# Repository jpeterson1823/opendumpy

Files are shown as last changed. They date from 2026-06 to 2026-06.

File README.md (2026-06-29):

# OpenDumpy: GB/C Dumping Tool

## What is this?
OpenDumpy is an open-source Gameboy and Gameboy Color cartridge dumper.

Planned Features:
- ROM Dump
- SRAM Dump
- SRAM Uploading from file
- Custom Open-Source USB Communication protocol
  - Will have FOSS software interface included in this repo.
- Lots of docs!

## Current Fabrication Status Status

OpenDumpy v1 boards are on order with PCBWay, expected by the middle of July 2026.

Firmware design is in progress. Actual programming to come soon.

## Setup & Building the UF2

### Install Required Packages

For Arch Linux:
- `cmake`
- `python`
- `base-devel`
- `arm-none-eabi-gcc`
- `arm-none-eabi-newlib`
- `arm-none-eabi-binutils`

For apt-based systems:
- `cmake`
- `python3`
- `build-essential`
- `gcc-arm-none-eabi`
- `libnewlib-arm-none-eabi`
- `libstdc++-arm-none-eabi-newlib`

### Cloning the Repo

When cloning this repo, make sure to _recursively_ initialize all submodules:

```
git clone https://github.com/jpeterson1823/opendumpy.git
cd opendumpy
git submodule update --init --recursive
```

### Compiling the Firmware

Assuming all package dependencies have been installed, building should be completed with CMake and Make.

It is recommended to create a build folder as to not muddy up the file tree:

```
mkdir firmware/build
cd firmware/build
cmake ..
make -j4
```

### Uploading the Firmware

Press the BOOTSEL button on OpenDumpy, then plug into USB port of machine. It will mount as a USB drive. Upload the built `opendumpy.uf2` file to the mounted drive. Voila!

## Images

### OpenDumpy v1
<div>
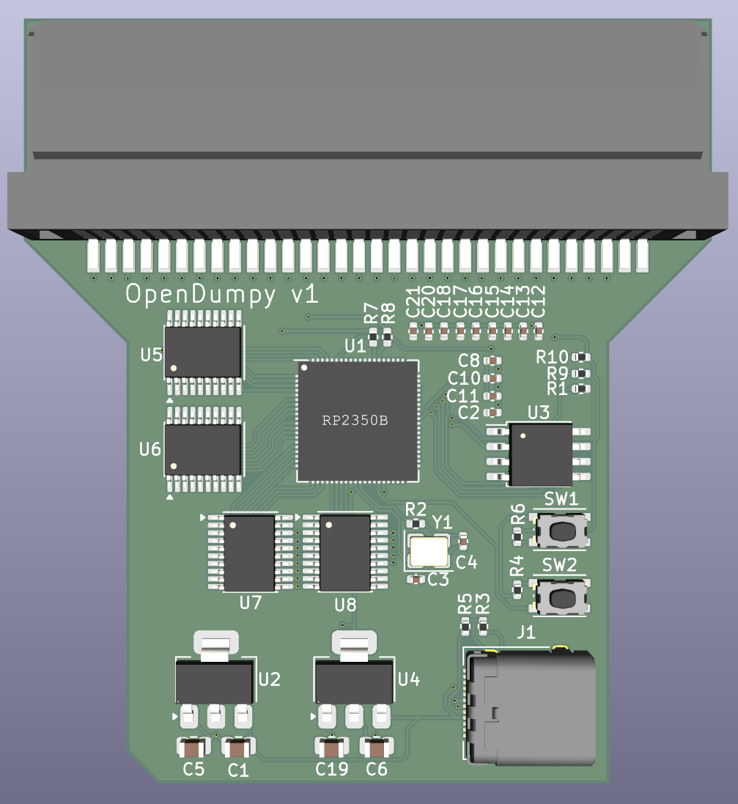
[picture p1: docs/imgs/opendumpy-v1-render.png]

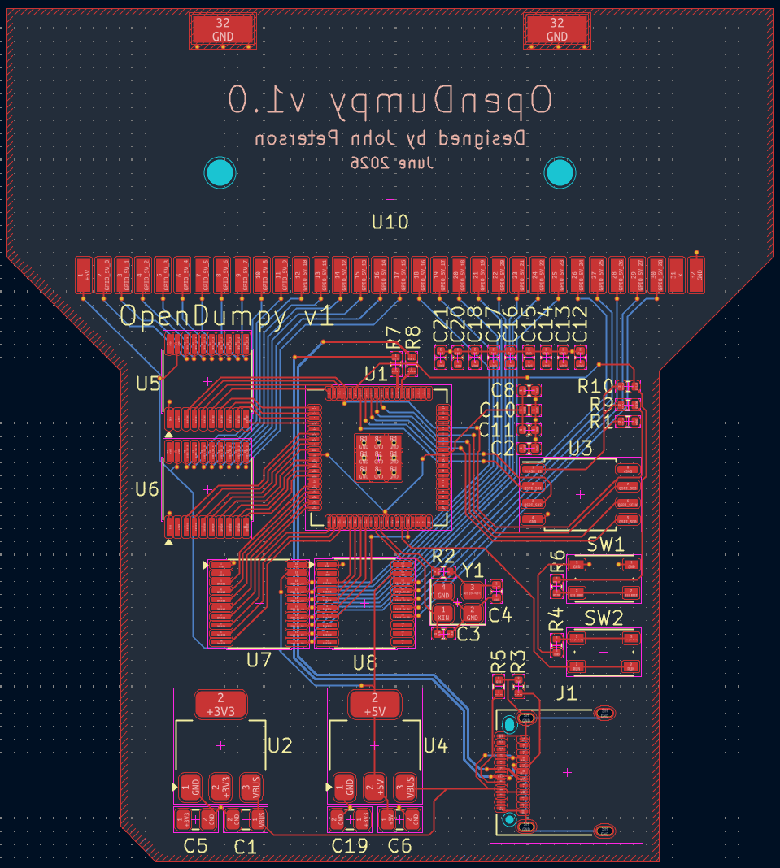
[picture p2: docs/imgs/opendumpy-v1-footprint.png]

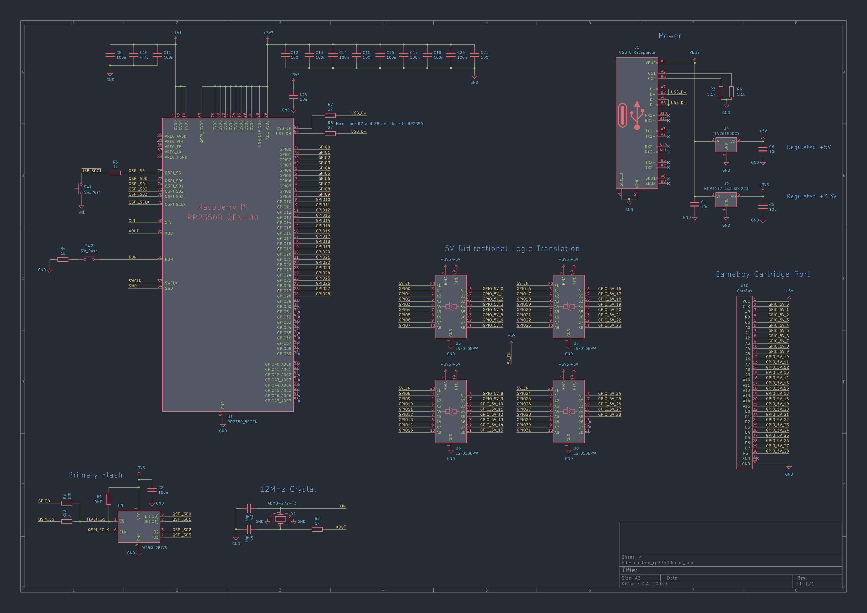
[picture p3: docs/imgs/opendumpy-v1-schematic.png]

</div>

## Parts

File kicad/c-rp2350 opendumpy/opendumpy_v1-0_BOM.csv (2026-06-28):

Id | Designator | Footprint | Quantity | Designation | Supplier and ref
1 | C1, C5, C6, C19 | C_0805_2012Metric | 4 | 10u
2 | C2, C8, C11, C12, C13, C14, C15, C16, C17, C18, C20, C21 | C_0402_1005Metric | 12 | 100n
3 | C3, C4 | C_0402_1005Metric | 2 | 15p
4 | C10 | C_0402_1005Metric | 1 | 4.7u
5 | J1 | USB_C_Receptacle_Amphenol_12401610E4-2A | 1 | USB_C_Receptacle
6 | R1, R9 | R_0402_1005Metric | 2 | DNF
7 | R2, R4, R6 | R_0402_1005Metric | 3 | 1k
8 | R3, R5 | R_0402_1005Metric | 2 | 5.1k
9 | R7, R8 | R_0402_1005Metric | 2 | 27
10 | R10 | R_0402_1005Metric | 1 | 0
11 | SW1, SW2 | SW_Push_1P1T_NO_Vertical_Wuerth_434133025816 | 2 | SW_Push
12 | U1 | RP2350-QFN-80-1EP_10x10_P0.4mm_EP3.4x3.4mm_ThermalVias | 1 | RP2350_80QFN
13 | U2 | SOT-223-3_TabPin2 | 1 | NCP1117-3.3_SOT223
14 | U3 | SOIC-8_5.23x5.23mm_P1.27mm | 1 | W25Q128JVS
15 | U4 | SOT-223-3_TabPin2 | 1 | TLV76150DCY
16 | U5, U6, U7, U8 | TSSOP-20_4.4x6.5mm_P0.65mm | 4 | LSF0108PW
17 | U10 | DSL_Cartridge_Reader | 1 | CartBus
18 | Y1 | Crystal_SMD_3225-4Pin_3.2x2.5mm | 1 | ABM8-272-T3

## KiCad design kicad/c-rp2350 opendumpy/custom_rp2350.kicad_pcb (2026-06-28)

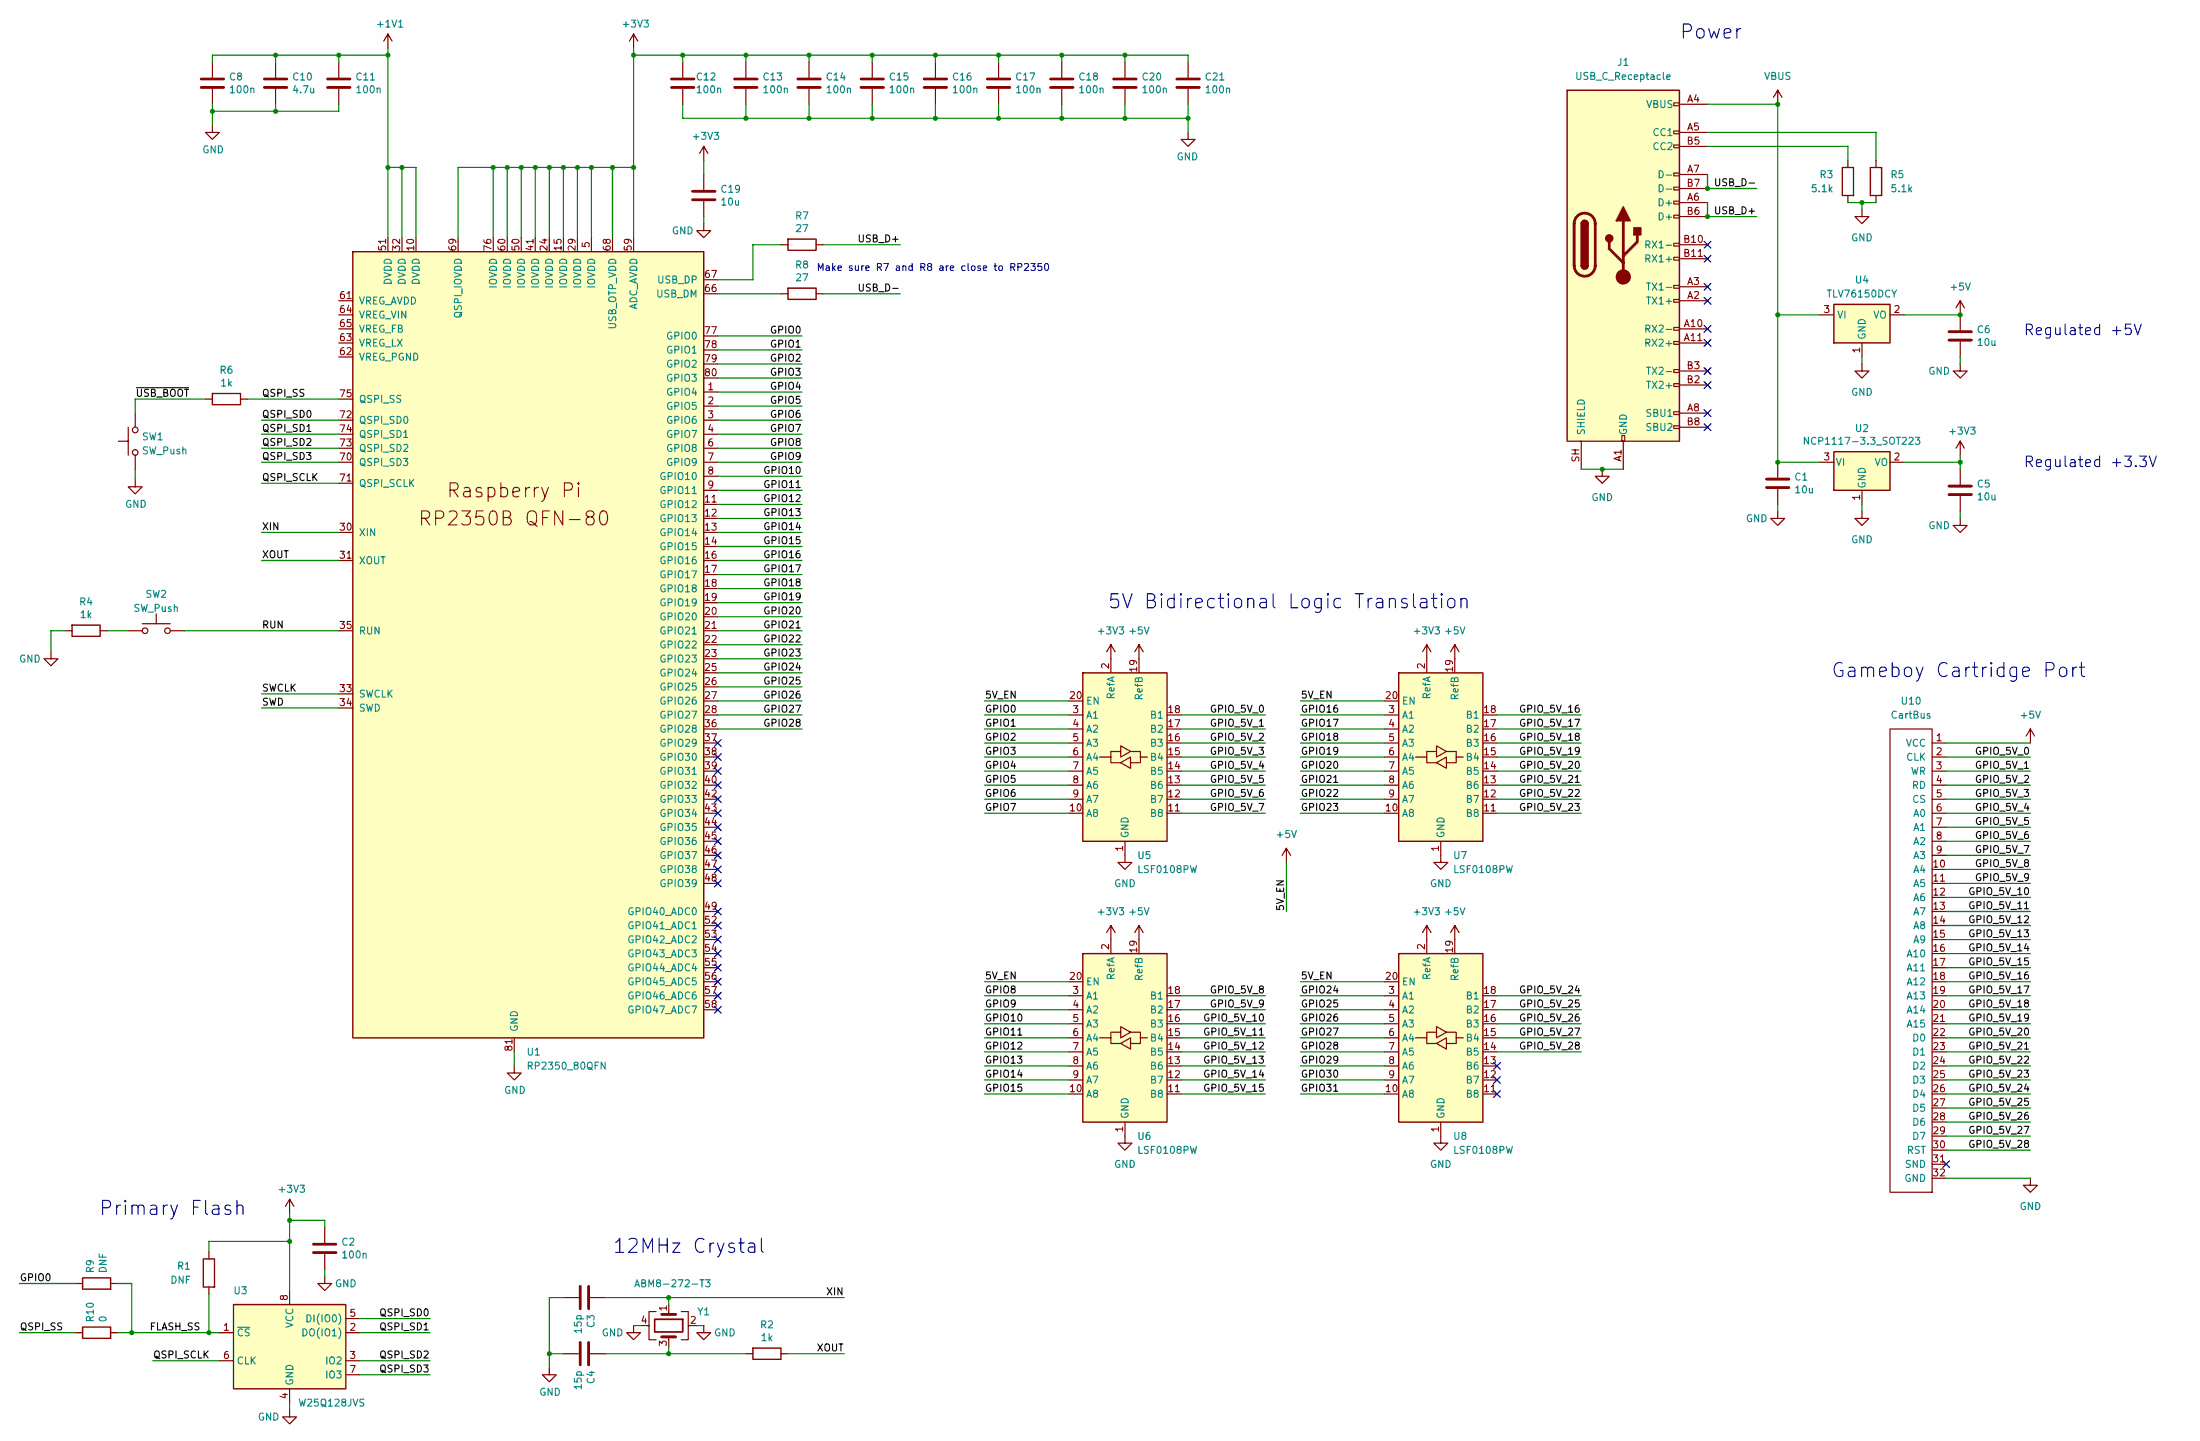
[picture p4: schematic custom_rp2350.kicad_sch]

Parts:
C1, C5, C6, C19: 10u; C_0805_2012Metric
C2, C8, C11, C12, C13, C14, C15, C16, C17, C18, C20, C21: 100n; C_0402_1005Metric
C3, C4: 15p; C_0402_1005Metric
C10: 4.7u; C_0402_1005Metric
J1: USB_C_Receptacle; USB_C_Receptacle_Amphenol_12401610E4-2A
R1, R9: DNF; R_0402_1005Metric
R2, R4, R6: 1k; R_0402_1005Metric
R3, R5: 5.1k; R_0402_1005Metric
R7, R8: 27; R_0402_1005Metric
R10: 0; R_0402_1005Metric
SW1, SW2: SW_Push; SW_Push_1P1T_NO_Vertical_Wuerth_434133025816
U1: RP2350_80QFN; RP2350-QFN-80-1EP_10x10_P0.4mm_EP3.4x3.4mm_ThermalVias
U2: NCP1117-3.3_SOT223; SOT-223-3_TabPin2
U3: W25Q128JVS; SOIC-8_5.23x5.23mm_P1.27mm
U4: TLV76150DCY; SOT-223-3_TabPin2
U5, U6, U7, U8: LSF0108PW; TSSOP-20_4.4x6.5mm_P0.65mm
U10: CartBus; DSL_Cartridge_Reader
Y1: ABM8-272-T3; Crystal_SMD_3225-4Pin_3.2x2.5mm

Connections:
+1V1: C8.1, C10.1, C11.1, U1.10 (DVDD), U1.32 (DVDD), U1.51 (DVDD)
+3V3: C2.1, C5.1, C12.1, C13.1, C14.1, C15.1, C16.1, C17.1, C18.1, C19.1, C20.1, C21.1, R1.1, U1.5 (IOVDD), U1.15 (IOVDD), U1.24 (IOVDD), U1.29 (IOVDD), U1.41 (IOVDD), U1.50 (IOVDD), U1.59 (ADC_AVDD), U1.60 (IOVDD), U1.68 (USB_OTP_VDD), U1.69 (QSPI_IOVDD), U1.76 (IOVDD), U2.2 (VO), U3.8 (VCC), U5.2 (RefA), U6.2 (RefA), U7.2 (RefA), U8.2 (RefA)
+5V: C6.1, U4.2 (VO), U5.19 (RefB), U5.20 (EN), U6.19 (RefB), U6.20 (EN), U7.19 (RefB), U7.20 (EN), U8.19 (RefB), U8.20 (EN), U10.1 (VCC)
/FLASH_SS: R1.2, R9.2, R10.2, U3.1 (~CS)
/GPIO0: R9.1, U1.77 (GPIO0), U5.3 (A1)
/GPIO1: U1.78 (GPIO1), U5.4 (A2)
/GPIO2: U1.79 (GPIO2), U5.5 (A3)
/GPIO3: U1.80 (GPIO3), U5.6 (A4)
/GPIO4: U1.1 (GPIO4), U5.7 (A5)
/GPIO5: U1.2 (GPIO5), U5.8 (A6)
/GPIO6: U1.3 (GPIO6), U5.9 (A7)
/GPIO7: U1.4 (GPIO7), U5.10 (A8)
/GPIO8: U1.6 (GPIO8), U6.3 (A1)
/GPIO9: U1.7 (GPIO9), U6.4 (A2)
/GPIO10: U1.8 (GPIO10), U6.5 (A3)
/GPIO11: U1.9 (GPIO11), U6.6 (A4)
/GPIO12: U1.11 (GPIO12), U6.7 (A5)
/GPIO13: U1.12 (GPIO13), U6.8 (A6)
/GPIO14: U1.13 (GPIO14), U6.9 (A7)
/GPIO15: U1.14 (GPIO15), U6.10 (A8)
/GPIO16: U1.16 (GPIO16), U7.3 (A1)
/GPIO17: U1.17 (GPIO17), U7.4 (A2)
/GPIO18: U1.18 (GPIO18), U7.5 (A3)
/GPIO19: U1.19 (GPIO19), U7.6 (A4)
/GPIO20: U1.20 (GPIO20), U7.7 (A5)
/GPIO21: U1.21 (GPIO21), U7.8 (A6)
/GPIO22: U1.22 (GPIO22), U7.9 (A7)
/GPIO23: U1.23 (GPIO23), U7.10 (A8)
/GPIO24: U1.25 (GPIO24), U8.3 (A1)
/GPIO25: U1.26 (GPIO25), U8.4 (A2)
/GPIO26: U1.27 (GPIO26), U8.5 (A3)
/GPIO27: U1.28 (GPIO27), U8.6 (A4)
/GPIO28: U1.36 (GPIO28), U8.7 (A5)
/GPIO29: U8.8 (A6)
/GPIO30: U8.9 (A7)
/GPIO31: U8.10 (A8)
/GPIO_5V_0: U5.18 (B1), U10.2 (CLK~)
/GPIO_5V_1: U5.17 (B2), U10.3 (WR)
/GPIO_5V_2: U5.16 (B3), U10.4 (RD)
/GPIO_5V_3: U5.15 (B4), U10.5 (CS)
/GPIO_5V_4: U5.14 (B5), U10.6 (A0)
/GPIO_5V_5: U5.13 (B6), U10.7 (A1)
/GPIO_5V_6: U5.12 (B7), U10.8 (A2)
/GPIO_5V_7: U5.11 (B8), U10.9 (A3)
/GPIO_5V_8: U6.18 (B1), U10.10 (A4)
/GPIO_5V_9: U6.17 (B2), U10.11 (A5)
/GPIO_5V_10: U6.16 (B3), U10.12 (A6)
/GPIO_5V_11: U6.15 (B4), U10.13 (A7)
/GPIO_5V_12: U6.14 (B5), U10.14 (A8)
/GPIO_5V_13: U6.13 (B6), U10.15 (A9)
/GPIO_5V_14: U6.12 (B7), U10.16 (A10)
/GPIO_5V_15: U6.11 (B8), U10.17 (A11)
/GPIO_5V_16: U7.18 (B1), U10.18 (A12)
/GPIO_5V_17: U7.17 (B2), U10.19 (A13)
/GPIO_5V_18: U7.16 (B3), U10.20 (A14)
/GPIO_5V_19: U7.15 (B4), U10.21 (A15)
/GPIO_5V_20: U7.14 (B5), U10.22 (D0)
/GPIO_5V_21: U7.13 (B6), U10.23 (D1)
/GPIO_5V_22: U7.12 (B7), U10.24 (D2)
/GPIO_5V_23: U7.11 (B8), U10.25 (D3)
/GPIO_5V_24: U8.18 (B1), U10.26 (D4)
/GPIO_5V_25: U8.17 (B2), U10.27 (D5)
/GPIO_5V_26: U8.16 (B3), U10.28 (D6)
/GPIO_5V_27: U8.15 (B4), U10.29 (D7)
/GPIO_5V_28: U8.14 (B5), U10.30 (RST)
/QSPI_SCLK: U1.71 (QSPI_SCLK), U3.6 (CLK)
/QSPI_SD0: U1.72 (QSPI_SD0), U3.5 (DI(IO0))
/QSPI_SD1: U1.74 (QSPI_SD1), U3.2 (DO(IO1))
/QSPI_SD2: U1.73 (QSPI_SD2), U3.3 (IO2)
/QSPI_SD3: U1.70 (QSPI_SD3), U3.7 (IO3)
/QSPI_SS: R6.1, R10.1, U1.75 (QSPI_SS)
/RUN: SW2.2, U1.35 (RUN)
/SWCLK: U1.33 (SWCLK)
/SWD: U1.34 (SWD)
/USB_D+: J1.A6 (D+), J1.B6 (D+), R7.1
/USB_D-: J1.A7 (D-), J1.B7 (D-), R8.1
/XIN: C3.1, U1.30 (XIN), Y1.1
/XOUT: R2.1, U1.31 (XOUT)
/~USB_BOOT: R6.2, SW1.2
GND: C1.2, C2.2, C3.2, C4.2, C5.2, C6.2, C8.2, C10.2, C11.2, C12.2, C13.2, C14.2, C15.2, C16.2, C17.2, C18.2, C19.2, C20.2, C21.2, J1.A1 (GND), J1.A12 (GND), J1.B1 (GND), J1.B12 (GND), J1.SH (SHIELD), R3.2, R4.2, R5.2, SW1.1, U1.81 (GND), U2.1 (GND), U3.4 (GND), U4.1 (GND), U5.1 (GND), U6.1 (GND), U7.1 (GND), U8.1 (GND), U10.32 (GND), Y1.2, Y1.4
unnamed: C4.1, R2.2, Y1.3
unnamed: J1.A5 (CC1), R5.1
unnamed: J1.B5 (CC2), R3.1
unnamed: R4.1, SW2.1
unnamed: R8.2, U1.66 (USB_DM)
unnamed: R7.2, U1.67 (USB_DP)
VBUS: C1.1, J1.A4 (VBUS), J1.A9 (VBUS), J1.B4 (VBUS), J1.B9 (VBUS), U2.3 (VI), U4.3 (VI)

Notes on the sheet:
Regulated +5V
Make sure R7 and R8 are close to RP2350
5V Bidirectional Logic Translation
Regulated +3.3V
Power
Gameboy Cartridge Port
Primary Flash
12MHz Crystal

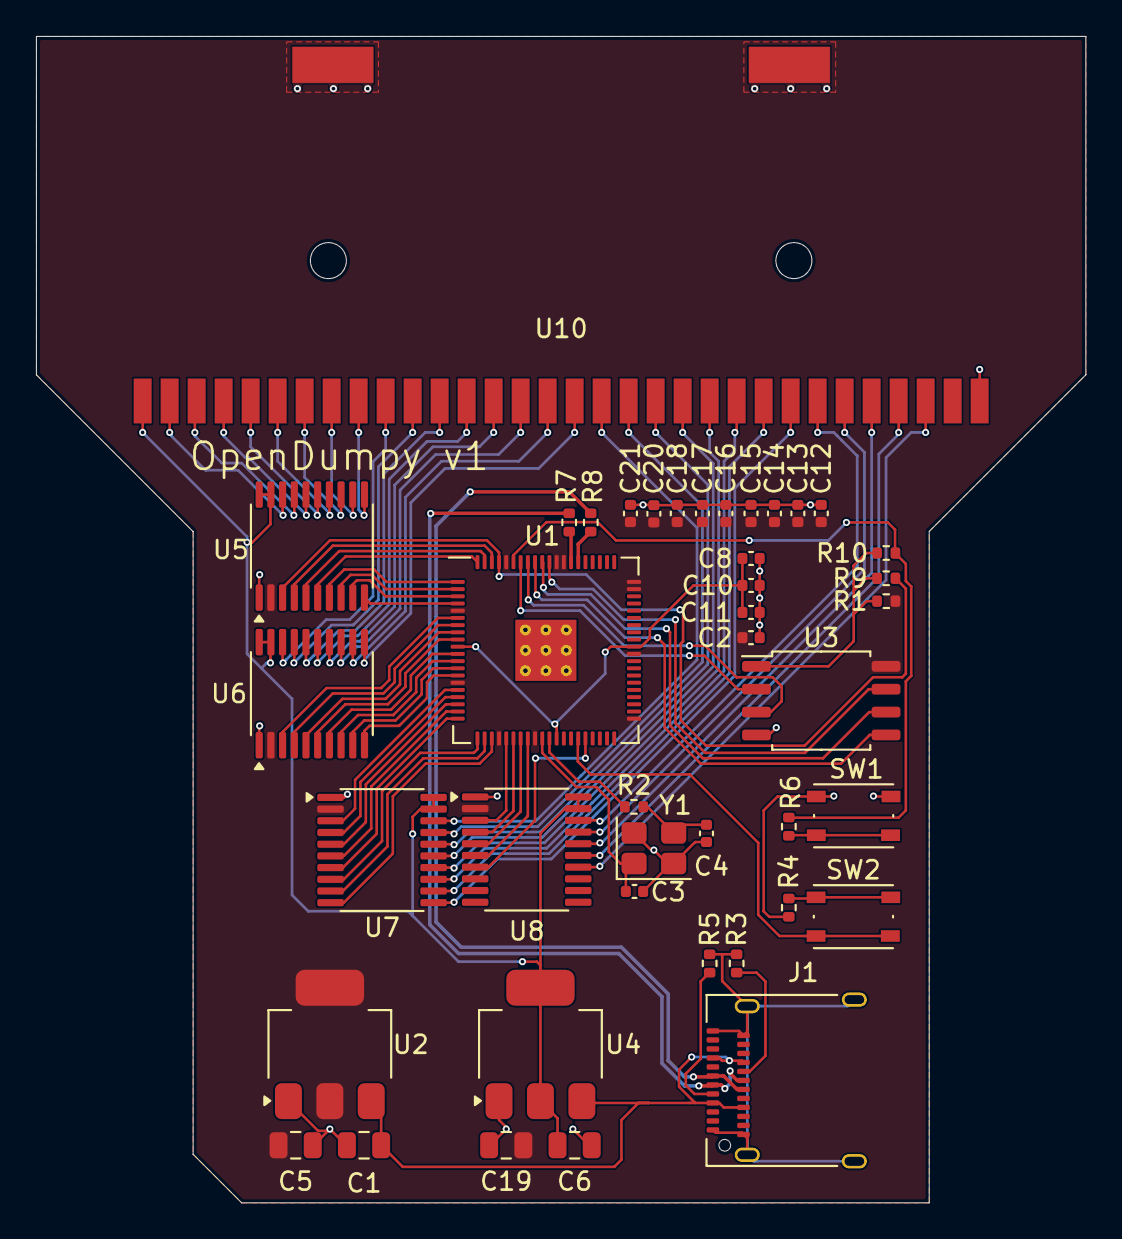
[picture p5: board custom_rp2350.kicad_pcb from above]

Board: 2 copper layers, 58.3 x 64.8 mm, 42 parts (0 on the bottom side), 82 nets.

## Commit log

2026-06-28 Pushing Current Progress
    Current PCB design that's on order with all current documentation
    [custom_rp2350.kicad_pcb, custom_rp2350.kicad_sch, custom_rp2350.rev0.kicad_pcb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]
2026-07-15 Pushing current progress.
2026-08-28 Uploading OpenDumpy v3 Progress
    Completed new PCB design, along with added components (LCD, MicroSD).
2026-08-30 Updated README and added OpenDumpy v3 BOM
